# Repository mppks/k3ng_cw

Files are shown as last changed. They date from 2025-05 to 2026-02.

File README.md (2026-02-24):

# K3NG CW keyer yet another version...

## Schematic K3NG CW keyer
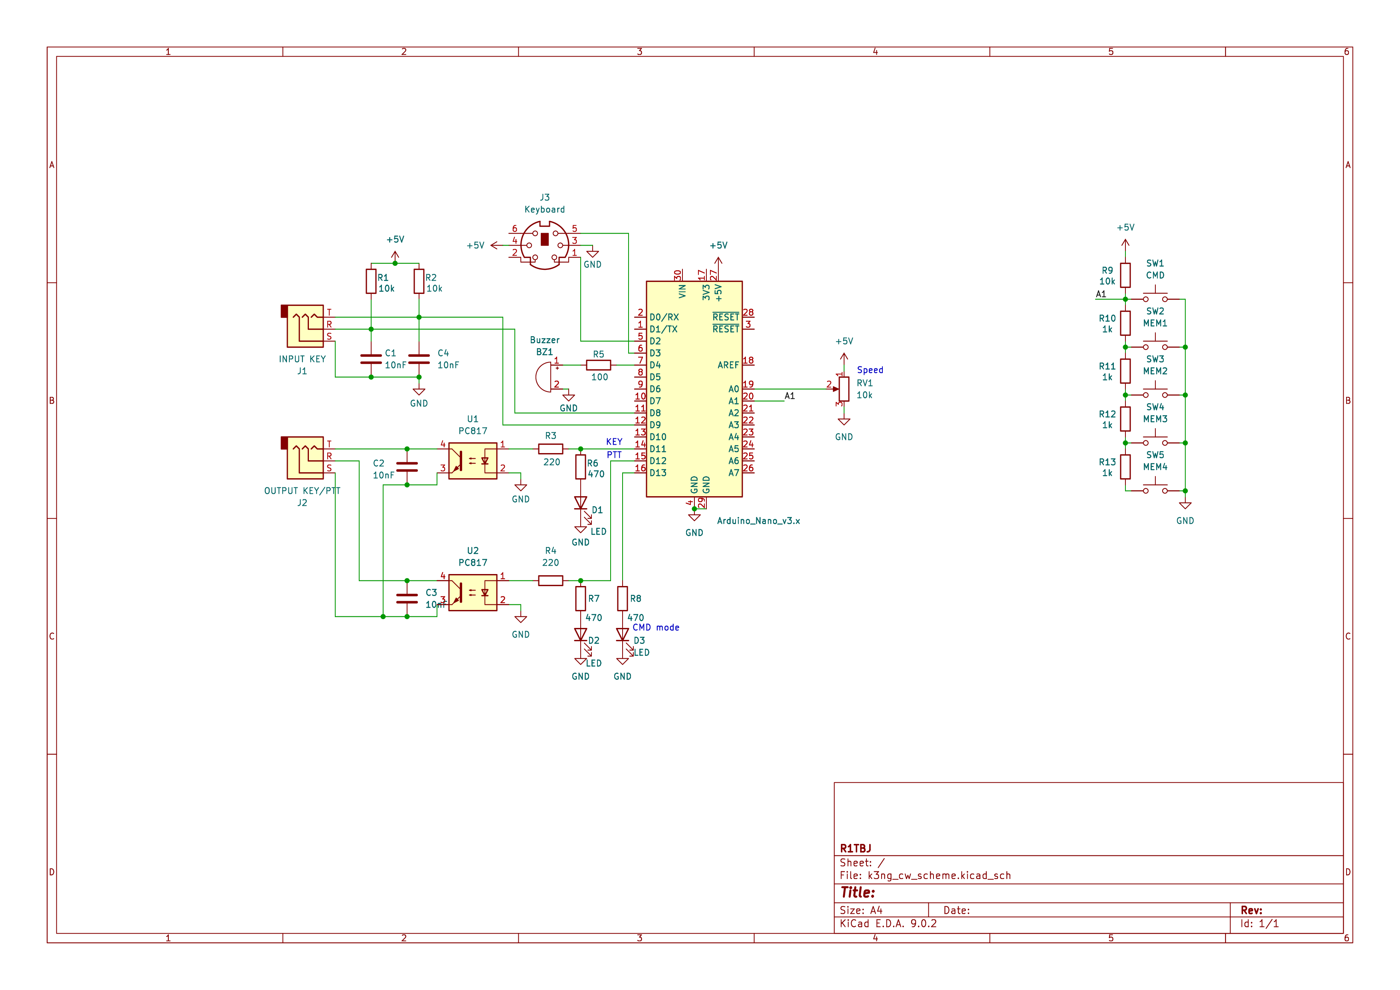
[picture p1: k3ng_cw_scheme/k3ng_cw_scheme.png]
Schematic K3NG CW keyer


## Applying my settings
To use my keyer settings, copy the files from the _r1tbj_settings_ directory to the original [k3ng firmware](https://github.com/k3ng/k3ng_cw_keyer) directory and add the following line to the **keyer_hardware.h** file

```C
#define HARDWARE_R1TBJ
```

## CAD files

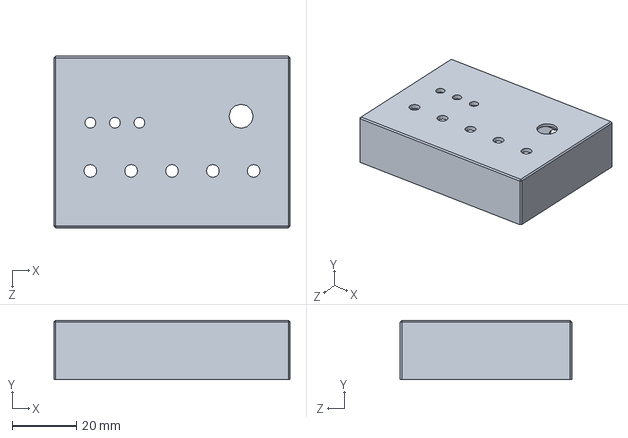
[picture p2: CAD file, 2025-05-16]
k3ng_cw_body/k3ng_case_top.SLDPRT
73.4 x 18.5 x 53.4 mm

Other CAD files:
k3ng_cw_body/k3ng_case_bottom.SLDPRT
k3ng_cw_body/k3ng_case_bottom.STL
k3ng_cw_body/k3ng_case_top.STL

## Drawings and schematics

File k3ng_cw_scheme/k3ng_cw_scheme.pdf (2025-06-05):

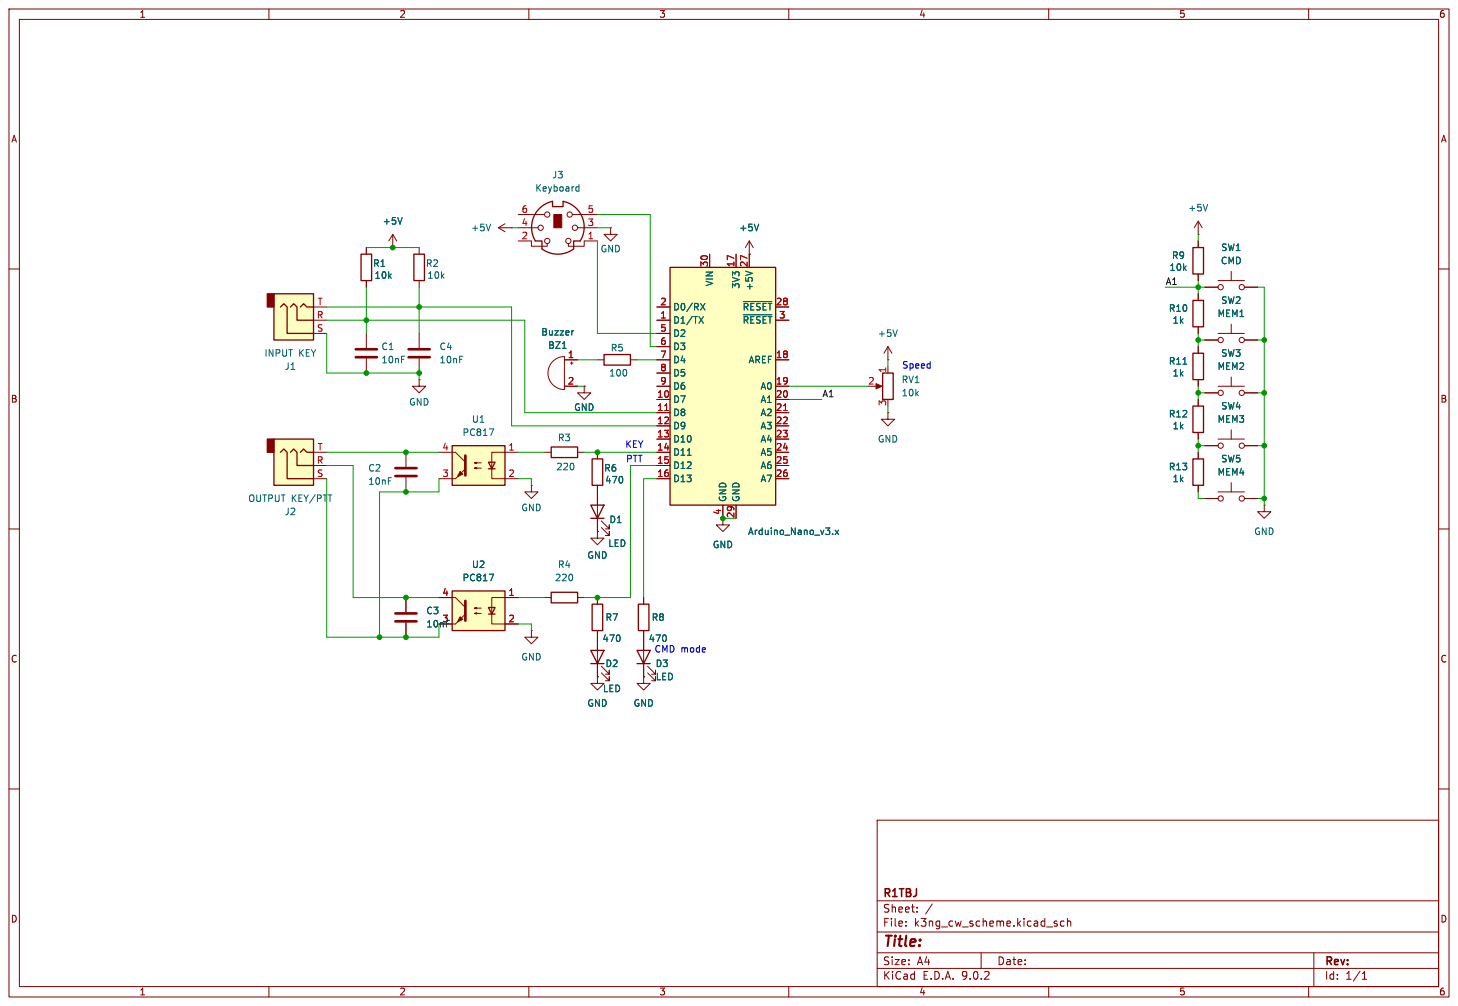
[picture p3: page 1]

Id: 1/1 Title: File: k3ng_cw_scheme.kicad_sch Sheet: / R1TBJ R6

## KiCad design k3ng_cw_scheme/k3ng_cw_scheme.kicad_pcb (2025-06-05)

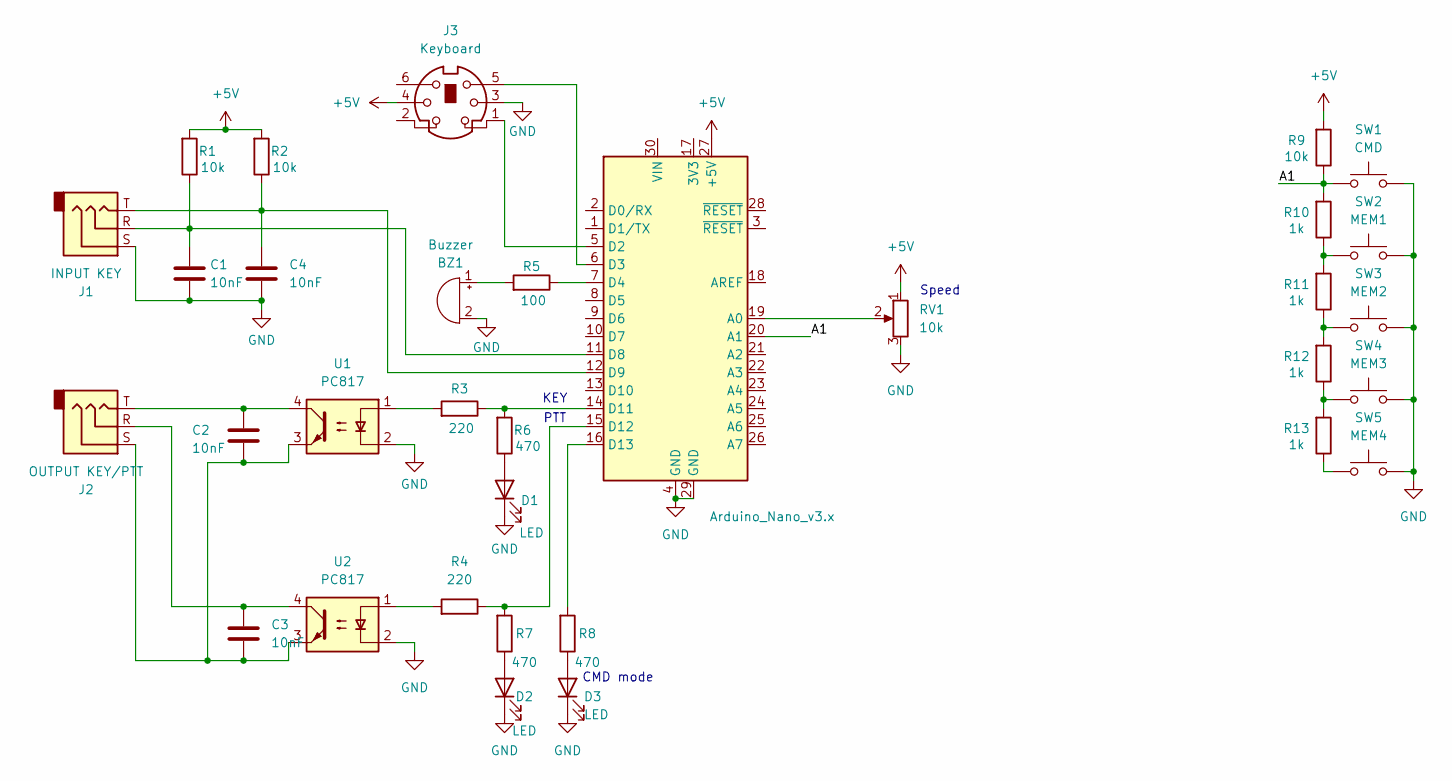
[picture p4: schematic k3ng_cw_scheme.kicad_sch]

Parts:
A1: Arduino_Nano_v3.x; Arduino_Nano
BZ1: Buzzer; Buzzer_12x9.5RM7.6
C1, C2, C3, C4: 10nF; C_Disc_D5.0mm_W2.5mm_P2.50mm
D1, D2, D3: LED; LED_D3.0mm
J1: INPUT KEY; Jack_3.5mm_CUI_SJ1-3525N_Horizontal
J2: OUTPUT KEY/PTT; Jack_3.5mm_CUI_SJ1-3525N_Horizontal
J3: Keyboard; Connector_Mini-DIN_Female_6Pin_2rows
R1, R2: 10k; R_Axial_DIN0204_L3.6mm_D1.6mm_P5.08mm_Vertical
R3, R4: 220; R_Axial_DIN0204_L3.6mm_D1.6mm_P5.08mm_Vertical
R5: 100; R_Axial_DIN0204_L3.6mm_D1.6mm_P5.08mm_Vertical
R6, R7, R8: 470; R_Axial_DIN0204_L3.6mm_D1.6mm_P5.08mm_Vertical
R9: 10k; R_Axial_DIN0207_L6.3mm_D2.5mm_P10.16mm_Horizontal
R10, R11, R12, R13: 1k; R_Axial_DIN0207_L6.3mm_D2.5mm_P10.16mm_Horizontal
RV1: 10k; Potentiometer_Alpha_RD901F-40-00D_Single_Vertical
SW1: CMD; SW_SPST_Omron_B3F-50xx
SW2: MEM1; SW_SPST_Omron_B3F-50xx
SW3: MEM2; SW_SPST_Omron_B3F-50xx
SW4: MEM3; SW_SPST_Omron_B3F-50xx
SW5: MEM4; SW_SPST_Omron_B3F-50xx
U1, U2: PC817; DIP-4_W7.62mm

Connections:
+5V: A1.27 (+5V), J3.4, R1.2, R2.2, R9.2, RV1.1
/A1: A1.20 (A1), R9.1, R10.2, SW1.1
GND: A1.4 (GND), A1.29 (GND), BZ1.2 (-), C1.2, C4.2, D1.1 (K), D2.1 (K), D3.1 (K), J1.S, J3.3, RV1.3, SW1.2, SW2.2, SW3.2, SW4.2, SW5.2, U1.2, U2.2
unnamed: A1.19 (A0), RV1.2
unnamed: A1.5 (D2), J3.1
unnamed: A1.6 (D3), J3.5
unnamed: A1.7 (D4), R5.1
unnamed: A1.11 (D8), C1.1, J1.R, R1.1
unnamed: A1.12 (D9), C4.1, J1.T, R2.1
unnamed: A1.14 (D11), R3.1, R6.2
unnamed: A1.15 (D12), R4.1, R7.2
unnamed: A1.16 (D13), R8.2
unnamed: BZ1.1 (+), R5.2
unnamed: C2.1, J2.T, U1.4
unnamed: C2.2, C3.2, J2.S, U1.3, U2.3
unnamed: C3.1, J2.R, U2.4
unnamed: D1.2 (A), R6.1
unnamed: D2.2 (A), R7.1
unnamed: D3.2 (A), R8.1
unnamed: R3.2, U1.1
unnamed: R4.2, U2.1
unnamed: R10.1, R11.2, SW2.1
unnamed: R11.1, R12.2, SW3.1
unnamed: R12.1, R13.2, SW4.1
unnamed: R13.1, SW5.1

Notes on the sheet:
KEY
CMD mode
PTT
Speed

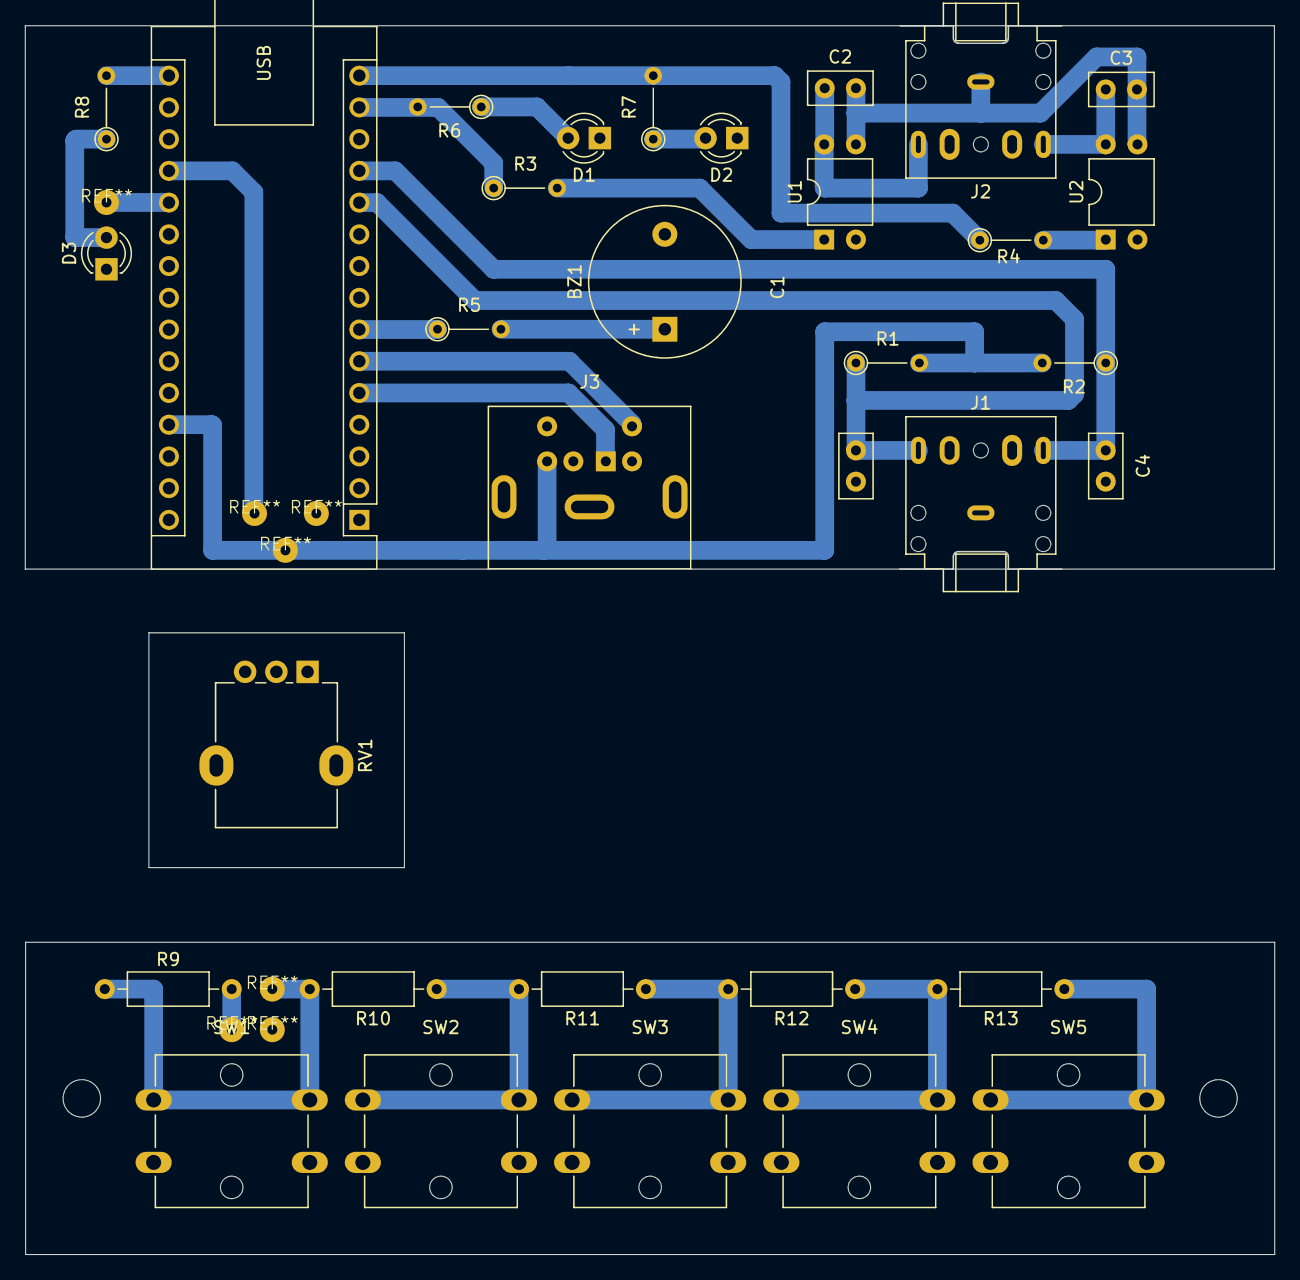
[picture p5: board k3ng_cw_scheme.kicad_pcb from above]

Board: 2 copper layers, 100.0 x 98.4 mm, 33 parts (0 on the bottom side), 25 nets.

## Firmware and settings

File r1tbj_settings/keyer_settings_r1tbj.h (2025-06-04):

// Initial and hardcoded settings
#define initial_speed_wpm 26             // "factory default" keyer speed setting
#define initial_command_mode_speed_wpm 20 // "factory default" command mode speed setting 
#define initial_sidetone_freq 600        // "factory default" sidetone frequency setting
#define sidetone_hz_limit_low 299
#define sidetone_hz_limit_high 2001
#define hz_high_beep 1500                // frequency in hertz of high beep
#define hz_low_beep 400                  // frequency in hertz of low beep
#define initial_dah_to_dit_ratio 300     // 300 = 3 / normal 3:1 ratio
#define initial_ptt_lead_time_tx1 0         // PTT lead time in mS
#define initial_ptt_tail_time_tx1 10         // PTT tail time in mS
#define initial_ptt_lead_time_tx2 0         // PTT lead time in mS
#define initial_ptt_tail_time_tx2 10         // PTT tail time in mS
#define initial_ptt_lead_time_tx3 0         // PTT lead time in mS
#define initial_ptt_tail_time_tx3 10         // PTT tail time in mS
#define initial_ptt_lead_time_tx4 0         // PTT lead time in mS
#define initial_ptt_tail_time_tx4 10         // PTT tail time in mS
#define initial_ptt_lead_time_tx5 0         // PTT lead time in mS
#define initial_ptt_tail_time_tx5 10         // PTT tail time in mS
#define initial_ptt_lead_time_tx6 0         // PTT lead time in mS
#define initial_ptt_tail_time_tx6 10         // PTT tail time in mS
#define initial_qrss_dit_length 1        // QRSS dit length in seconds
#define initial_pot_wpm_low_value 13     // Potentiometer WPM fully CCW
#define initial_pot_wpm_high_value 35    // Potentiometer WPM fully CW
#define wpm_limit_low 5
#define wpm_limit_high 60
#define potentiometer_change_threshold 0.9 // don't change the keyer speed until pot wpm has changed more than this
#define send_buffer_size 150
#define default_length_letterspace 3
#define default_length_wordspace 7
#define default_keying_compensation 0    // number of milliseconds to extend all dits and dahs - for QSK on boatanchors
#define default_first_extension_time 0   // number of milliseconds to extend first sent dit or dah
#define default_pot_full_scale_reading 1023
#define default_weighting 50             // 50 = weighting factor of 1 (normal)
#define default_ptt_hang_time_wordspace_units 0.0
#define winkey_c0_wait_time 1            // the number of milliseconds to wait to send 0xc0 byte after send buffer has been sent
#define winkey_command_timeout_ms 5000
#define winkey_discard_bytes_startup 3   // this is used if OPTION_WINKEY_DISCARD_BYTES_AT_STARTUP is enabled above
#define winkey_xoff_threshold 20         // the number of chars in the buffer when we begin sending XOFFs
#define winkey_xon_threshold 10          // the number of chars in the buffer below which we deactivate XOFF
#define default_memory_repeat_time 3000  // time in milliseconds
#define LCD_COLUMNS 11
#define LCD_ROWS 4
#define lcd_i2c_address_mathertel_PCF8574 0x27             // I2C address of display for FEATURE_LCD_MATHERTEL_PCF8574
#define lcd_i2c_address_fdebrander_lcd 0x27                // I2C address of display for FEATURE_LCD_I2C_FDEBRABANDER
#define lcd_i2c_address_ydv1_lcd 0x27                      // I2C address of display for FEATURE_LCD_YDv1
//#define lcd_i2c_address_ydv1_lcd 0x38                    // I2C address of display for FEATURE_LCD_YDv1
#define lcd_i2c_address_sainsmart_lcd 0x27                // I2C address of display for FEATURE_LCD_SAINSMART_I2C 
#define oled_i2c_address_ssd1306 0x3C                     // I2C address of display for FEATURE_OLED_SSD1306
#define lcd_i2c_address_twiliquidcrystal_lcd 0x27                // I2C address of display for FEATURE_LCD_TWILIQUIDCRYSTAL 
#define hell_pixel_microseconds 4025
#define program_memory_limit_consec_spaces 1
#define serial_leading_zeros 1            // set to 1 to activate leading zeros in serial numbers (i.e. #1 = 001)
#define serial_cut_numbers 0              // set to 1 to activate cut numbers in serial numbers (i.e. #10 = 1T, #19 = 1N)
#define go_to_sleep_inactivity_time 10    // minutes - FEATURE_SLEEP
#define dim_backlight_inactive_time 5     // minutes - FEATURE_LCD_BACKLIGHT_AUTO_DIM
#define default_cmos_super_keyer_iambic_b_timing_percent 33 // use with FEATURE_CMOS_SUPER_KEYER_IAMBIC_B_TIMING; should be between 0 to 99 % (0% = true iambic b;100% = iambic a behavior)
#define default_cw_echo_timing_factor 1.75 // "factory default" setting
#define default_autospace_timing_factor 2.0 // "factory default" setting
#define winkey_paddle_echo_buffer_decode_timing_factor 0.25
#define potentiometer_always_on 0
#define ptt_interlock_check_every_ms 100
#define ptt_interlock_active_state HIGH
#define unknown_cw_character '*'
#define cli_paddle_echo_on_at_boot 1
#define cli_straight_key_echo_on_at_boot 1
#define tx_key_dit_and_dah_pins_active_state HIGH
#define tx_key_dit_and_dah_pins_inactive_state LOW
#define potentiometer_check_interval_ms 150
#define potentiometer_reading_threshold 1
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

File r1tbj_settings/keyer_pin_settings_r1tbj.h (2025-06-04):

/* Pins - you must review these and configure ! */
#ifndef keyer_pin_settings_h
#define keyer_pin_settings_h

#define paddle_left 8
#define paddle_right 9
#define tx_key_line_1 11       // (high = key down/tx on)
#define tx_key_line_2 12
#define tx_key_line_3 0
#define tx_key_line_4 0
#define tx_key_line_5 0
#define tx_key_line_6 0
#define sidetone_line 4         // connect a speaker for sidetone
#define potentiometer A0        // Speed potentiometer (0 to 5 V) Use pot from 1k to 10k
#define ptt_tx_1 0              // PTT ("push to talk") lines
#define ptt_tx_2 0              //   Can be used for keying fox transmitter, T/R switch, or keying slow boatanchors
#define ptt_tx_3 0              //   These are optional - set to 0 if unused
#define ptt_tx_4 0
#define ptt_tx_5 0
#define ptt_tx_6 0
#define tx_key_dit 0            // if defined, goes active for dit (any transmitter) - customized with tx_key_dit_and_dah_pins_active_state and tx_key_dit_and_dah_pins_inactive_state
#define tx_key_dah 0            // if defined, goes active for dah (any transmitter) - customized with tx_key_dit_and_dah_pins_active_state and tx_key_dit_and_dah_pins_inactive_state

#define potentiometer_enable_pin 0  // if defined, the potentiometer will be enabled only when this pin is held low; set to 0 to ignore this pin

#ifdef FEATURE_BUTTONS
  #define analog_buttons_pin A1
  #define command_mode_active_led 13
#endif //FEATURE_BUTTONS

/*
FEATURE_SIDETONE_SWITCH
  Enabling this feature and an external toggle switch  adds switch control for playing cw sidetone.
  ST Switch status is displayed in the status command.  This feature will override the software control of the sidetone (\o).
  Arduino pin is assigned by SIDETONE_SWITCH 
*/

#ifdef FEATURE_SIDETONE_SWITCH
  #define SIDETONE_SWITCH 8
#endif //FEATURE_SIDETONE_SWITCH


//lcd pins
#if defined(FEATURE_LCD_4BIT) || defined(FEATURE_LCD_8BIT)
  #define lcd_rs A2
  #define lcd_enable 10  // pin 10 is used by Ethernet shield and will conflict with that
  #define lcd_d4 6
  #define lcd_d5 7
  #define lcd_d6 8
  #define lcd_d7 9
#endif //FEATURE_LCD_4BIT || defined(FEATURE_LCD_8BIT)

#if defined(FEATURE_LCD_8BIT) // addition four data lines for 8 bit LCD control
  #define lcd_d0 20
  #define lcd_d1 21
  #define lcd_d2 22
  #define lcd_d3 23
#endif //FEATURE_LCD_4BIT || defined(FEATURE_LCD_8BIT)

#ifdef FEATURE_LCD1602_N07DH
  #define lcd_rs 8
  #define lcd_enable 9
  #define lcd_d4 4
  #define lcd_d5 5
  #define lcd_d6 6
  #define lcd_d7 7
#endif //FEATURE_LCD1602_N07DH

//ps2 keyboard pins
#ifdef FEATURE_PS2_KEYBOARD
  #define ps2_keyboard_data 2
  #define ps2_keyboard_clock 3    // this must be on an interrupt capable pin!
#endif //FEATURE_PS2_KEYBOARD

// rotary encoder pins and options - rotary encoder code from Jim Balls M0CKE
#ifdef FEATURE_ROTARY_ENCODER
  #define OPTION_ENCODER_HALF_STEP_MODE     // Half-step mode?
  #define rotary_pin1 0                      // CW Encoder Pin
  #define rotary_pin2 0                    // CCW Encoder Pin
  #define OPTION_ENCODER_ENABLE_PULLUPS     // define to enable weak pullups.
#endif //FEATURE_ROTARY_ENCODER

#ifdef FEATURE_LED_RING
  #define led_ring_sdi    A10 //2    //Data
  #define led_ring_clk    A9 //3    //Clock
  #define led_ring_le     A8 //4    //Latch
#endif //FEATURE_LED_RING

#define correct_answer_led 0
#define wrong_answer_led 0

#ifdef FEATURE_PTT_INTERLOCK
  #define ptt_interlock 0  // this pin disables PTT and TX KEY
#endif //FEATURE_PTT_INTERLOCK

#ifdef FEATURE_STRAIGHT_KEY
  #define pin_straight_key 52
#endif //FEATURE_STRAIGHT_KEY

// FEATURE_CW_DECODER & OPTION_CW_DECODER_GOERTZEL_AUDIO_DETECTOR
// See https://github.com/k3ng/k3ng_cw_keyer/wiki/385-Feature:-CW-Decoder for details
#define cw_decoder_pin 0             // This is for use with external decoding hardware
#define cw_decoder_audio_input_pin 0 // This is for audio detection decoding using OPTION_CW_DECODER_GOERTZEL_AUDIO_DETECTOR; this must be an analog pin!
#define cw_decoder_indicator 0       // Output - goes HIGH when cw tone is detected by OPTION_CW_DECODER_GOERTZEL_AUDIO_DETECTOR

#if defined(FEATURE_COMPETITION_COMPRESSION_DETECTION)
  #define compression_detection_pin 13
#endif //FEATURE_COMPETITION_COMPRESSION_DETECTION

#if defined(FEATURE_SLEEP)
  #define keyer_awake 0
#endif

#if defined(FEATURE_LCD_BACKLIGHT_AUTO_DIM)
  #define keyer_power_led 0   // must be a PWM-capable pin
#endif

#if defined(FEATURE_CAPACITIVE_PADDLE_PINS)
  #define capactive_paddle_pin_inhibit_pin 0     // if this pin is defined and is set high, the capacitive paddle pins will switch to normal (non-capacitive) sensing mode
#endif

#ifdef FEATURE_4x4_KEYPAD
  #define Row3 33
  #define Row2 32
  #define Row1 31
  #define Row0 30
  #define Col3 37
  #define Col2 36
  #define Col1 35
  #define Col0 34
#endif

#ifdef FEATURE_3x4_KEYPAD
  #define Row3 33
  #define Row2 32
  #define Row1 31
  #define Row0 30
  #define Col2 36
  #define Col1 35
  #define Col0 34
#endif
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

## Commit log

2025-05-19 Add keyboard connector Start working on PCB
    [k3ng_cw_scheme.kicad_pcb, k3ng_cw_scheme.kicad_sch]
2025-06-03 Add some pads to pcb
    [k3ng_cw_scheme.kicad_pcb]
2025-06-05 Add scheme to pdf
    [k3ng_cw_scheme.kicad_pcb, k3ng_cw_scheme.kicad_sch]
2026-02-24 docs(README.md): add an electronic circuit to the description
